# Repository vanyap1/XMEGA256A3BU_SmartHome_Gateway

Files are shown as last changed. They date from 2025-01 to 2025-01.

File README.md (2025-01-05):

# XMEGA256A3BU_SmartHome_Gateway

## Опис проекту
Це шлюз для розумного будинку, який може з'єднувати різні типи пристроїв з різними інтерфейсами, передавати та буферизувати між ними інформацію, реалізувати власну логіку та багато іншого.

## Можливості
- Підтримка інтерфейсів: LAN, CAN, SPI, I2C, GPIO
- Релейні виходи та входи з оптичною розв'язкою
- SD карта для логів
- Веб сервер для керування

## Структура проекту
- **XMEGA_A3BU**: Основний код проекту
  - `main.c`: Головний файл програми
  - `driver/`: Драйвери для різних периферійних пристроїв
  - `libs/`: Бібліотеки для роботи з різними інтерфейсами та пристроями
- **eagle_src**: Схеми та плати проекту
  - `controller_V1.brd`: Файл плати
  - `controller_V1.sch`: Схема проекту

## Контролер
В проекті використовується контролер **XMEGA256A3BU**. Основні переваги цього контролера:
- Висока продуктивність завдяки 8/16-бітному процесору
- Велика кількість периферійних інтерфейсів
- Низьке енергоспоживання
- Вбудована підтримка USB

## Фото модуля
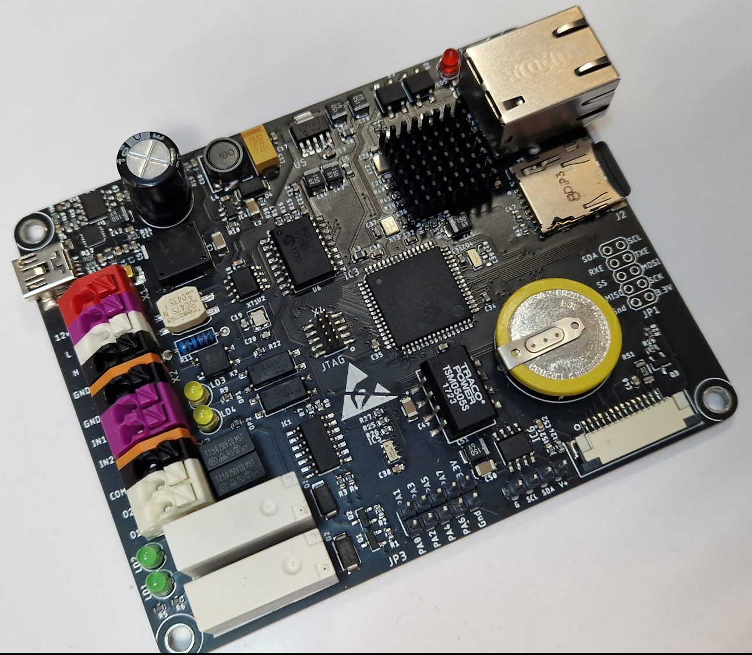
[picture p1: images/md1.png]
Фото модуля 1

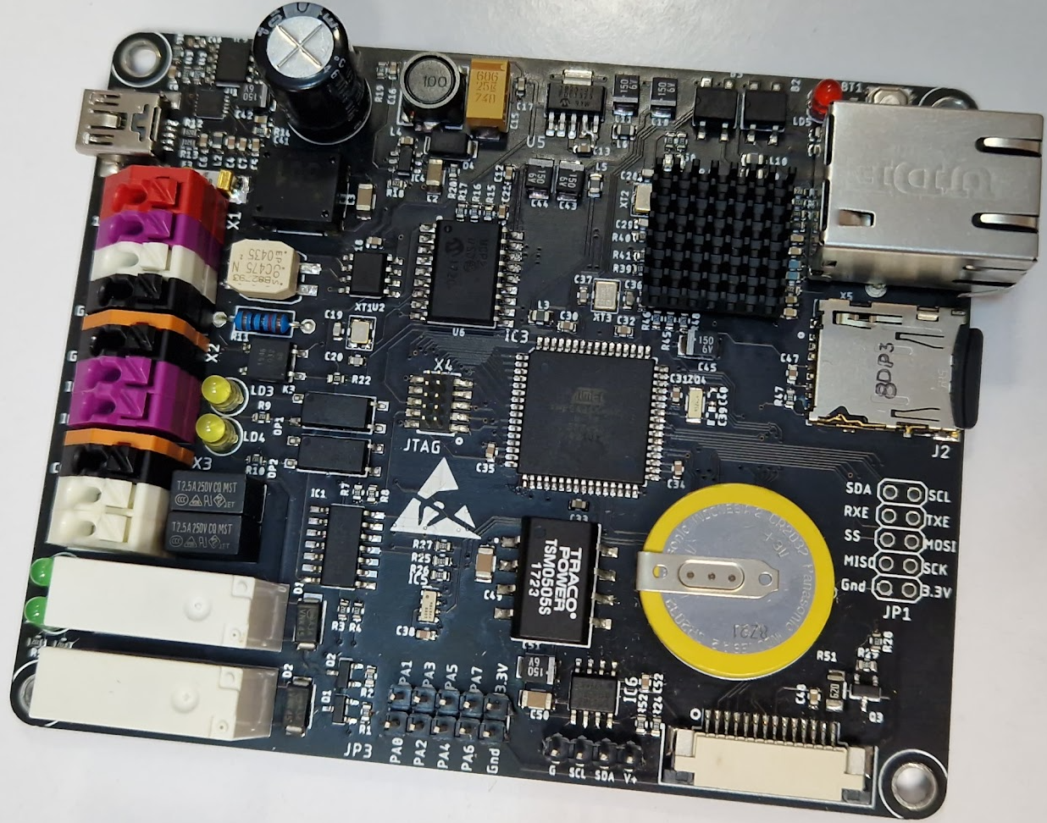
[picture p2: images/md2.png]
Фото модуля 2


## Інструкції по збірці
Для збірки проекту використовуйте Makefile, який знаходиться у директорії `XMEGA_A3BU/Debug/`.

```sh
cd XMEGA_A3BU/Debug/
make

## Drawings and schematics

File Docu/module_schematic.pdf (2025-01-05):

## FT234XD-R

# RTC_SDA USB

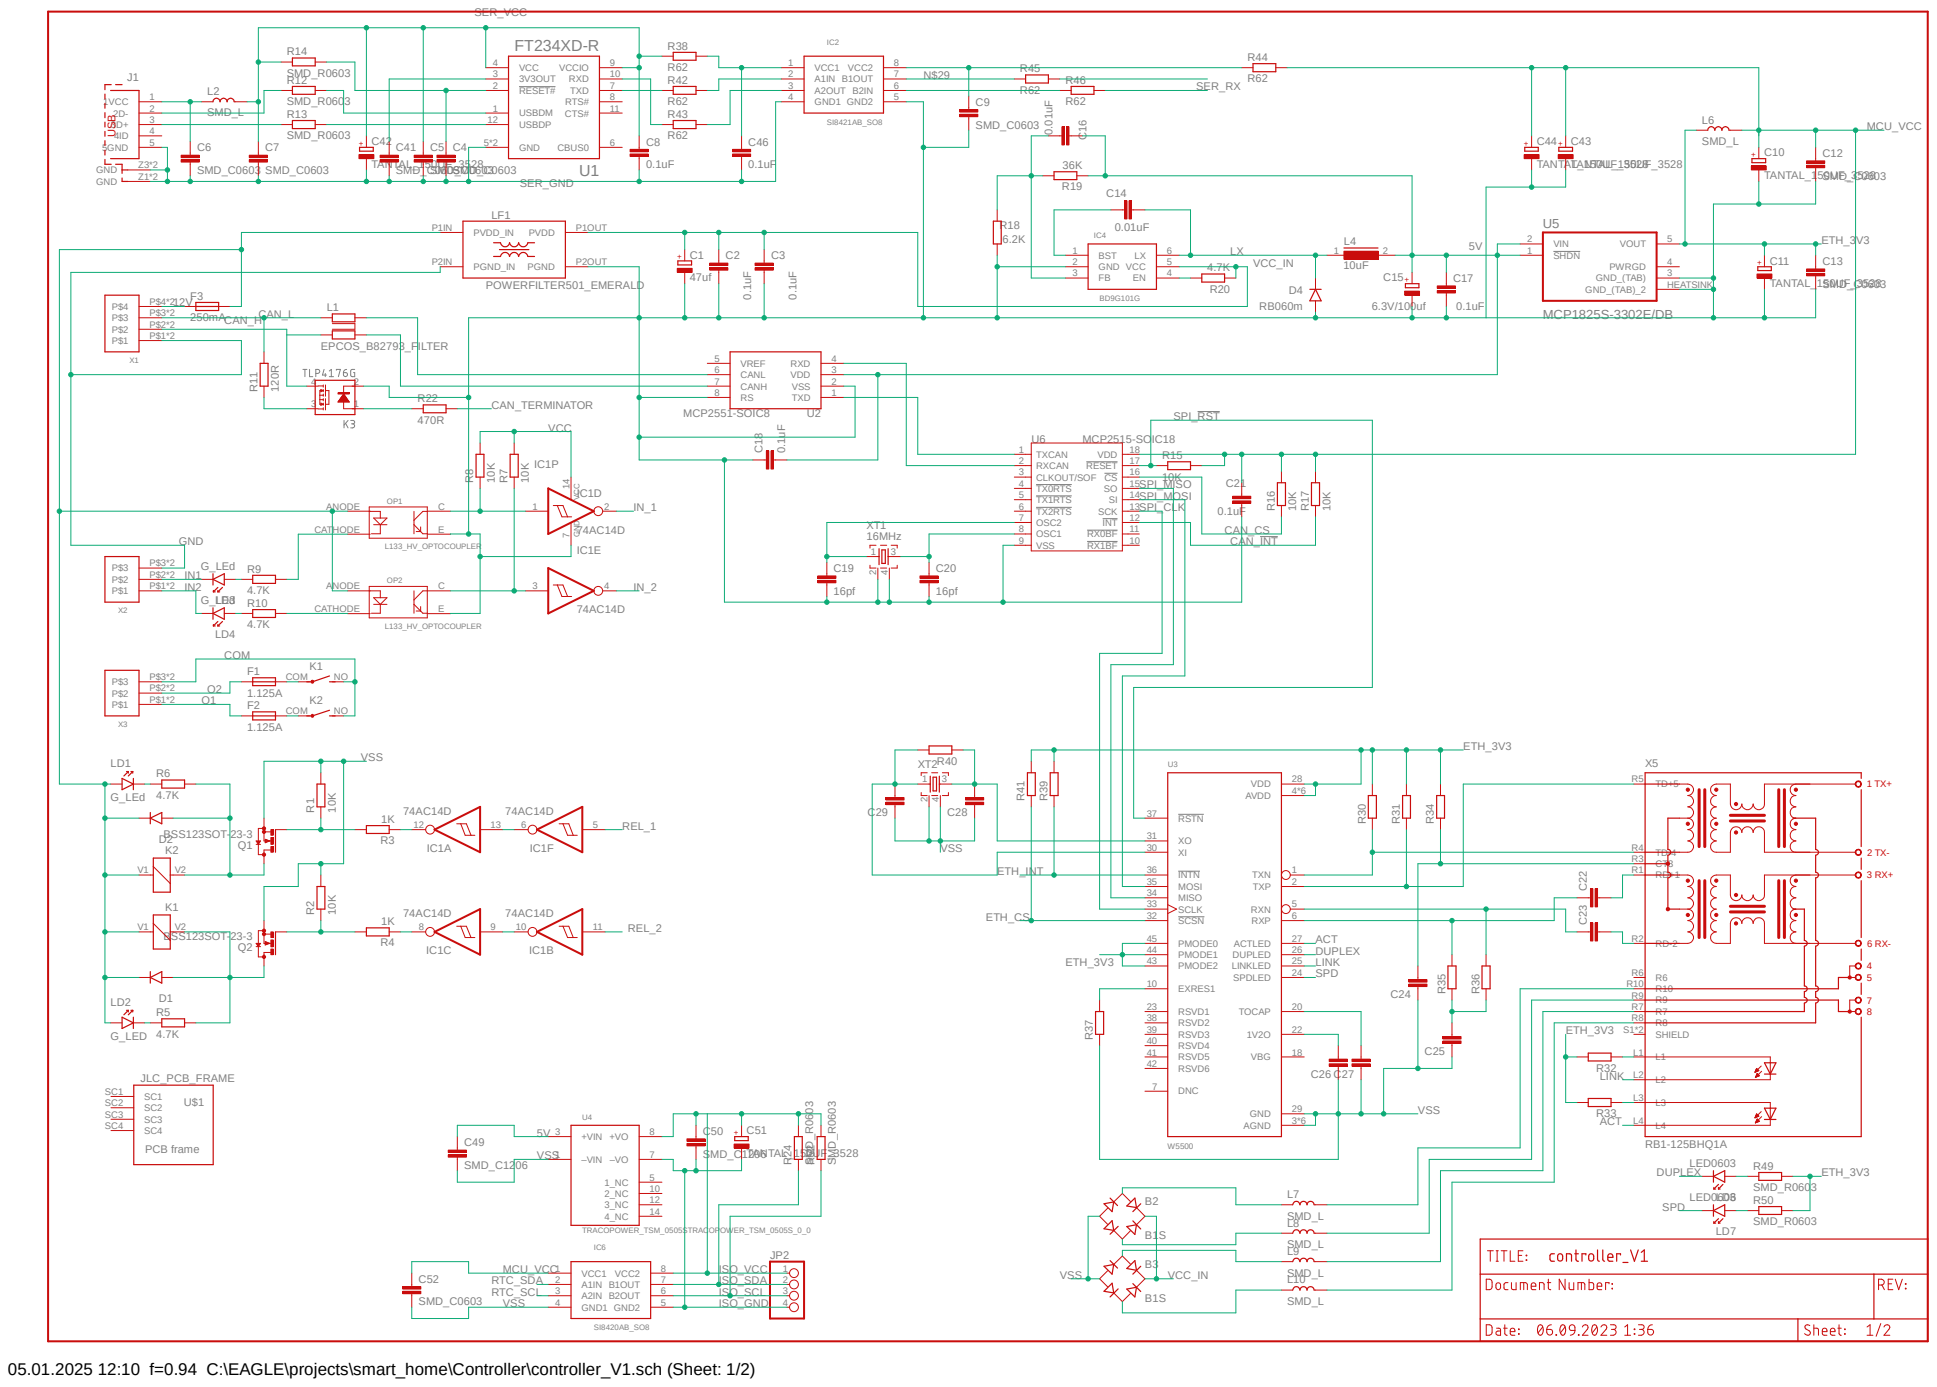
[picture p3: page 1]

05.01.2025 12:10 f=0.94 C:\EAGLE\projects\smart_home\Controller\controller_V1.sch (Sheet: 1/2)

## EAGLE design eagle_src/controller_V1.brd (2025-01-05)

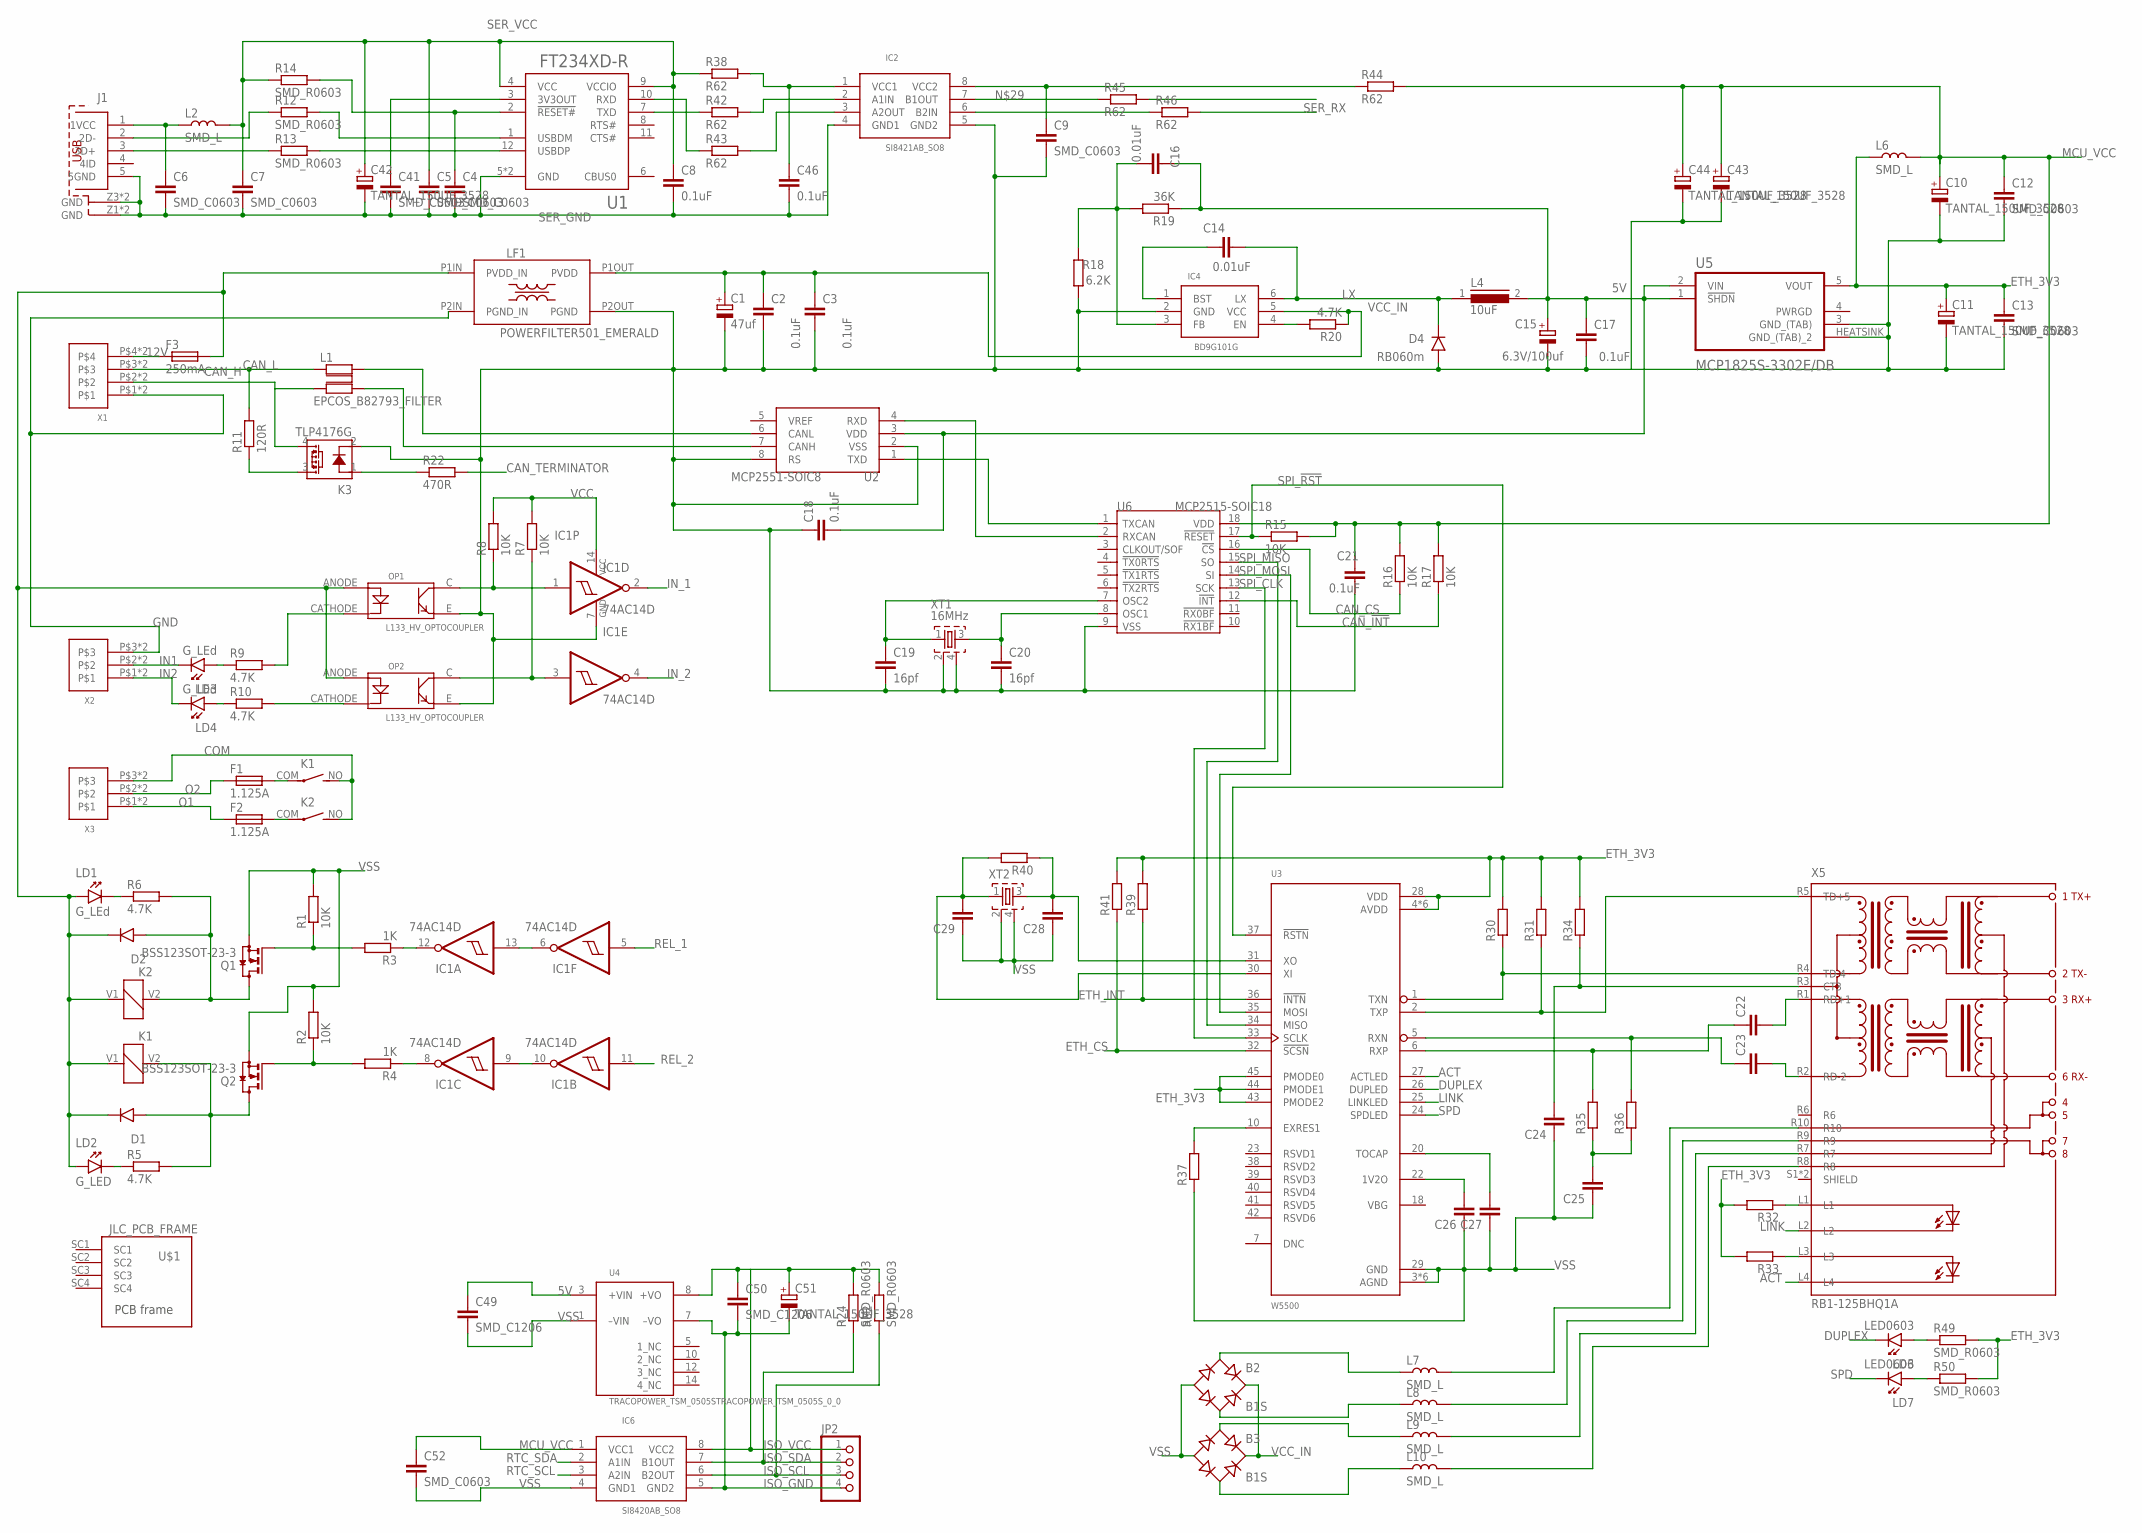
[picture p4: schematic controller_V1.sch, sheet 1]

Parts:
B2, B3: B1S; MBS
C1: 47uf; 5.08MM
C2, C3: 0.1uF; 1206
C4, C5, C6, C7, C9, C12, C13, C22, C23, C26, C27, C28, C29, C41, C52: SMD_C0603; 0603
C8, C17, C18, C21, C46: 0.1uF; 0603
C10, C11, C42, C43, C44, C51: TANTAL_150UF_3528; KA-3528ASYC
C14, C16: 0.01uF; 0603
C15: 6.3V/100uf; D/7343-31R
C19, C20: 16pf; 0603
C24: 0.1uf; 0603
C25: 10nf; 0603
C49, C50: SMD_C1206; 1206
D1, D2: D_MBRA340G; SMA403D
D4: RB060m; SMA403D
F1, F2: 1.125A; FUSE_DIP_2.5A250V
F3: 250mA; SMD_2410_FUSE_NOK
IC1: 74AC14D; SO14
IC2: SI8421AB_SO8; SO8
IC4: BD9G101G; SOT-23(6)
IC6: SI8420AB_SO8; SO8
J1: MINI_USB_TYP_B_@; 65100516121
JP2: PINHD-1X4; 1X04
K1, K2: 12-H1(610); 12-H1(610)_DIP
K3: TLP4176G; SOP04
L1: EPCOS_B82793_FILTER; EPCOS_FILTER
L2, L6, L7, L8, L9, L10: SMD_L; 0805
L4: 10uF; DR74
LD1, LD3, LD4: G_LEd; 3MM_DIP_LED
LD2: G_LED; 3MM_DIP_LED
LD6, LD7: LED0603; 0603_P
LF1: POWERFILTER501_EMERALD; POWERFILTER
OP1, OP2: L133_HV_OPTOCOUPLER; HV_OPTOCOUPLER_L133
Q1, Q2: BSS123SOT-23-3; SOT-23(3)
R1, R2, R7, R8, R15, R16, R17: 10K; 0603
R3, R4: 1K; 0603
R5, R6, R9, R10, R20: 4.7K; 0603
R11: 120R; VMTA55
R12, R13, R14, R24, R30, R31, R32, R33, R34, R35, R36, R37, R39, R40, R41, R49, R50, R52: SMD_R0603; 0603
R18: 6.2K; 0603
R19: 36K; 0603
R22: 470R; 0603
R38, R42, R43, R44, R45, R46: R62; 0603
U1: FT234XD-R; IC_FT234XD-R
U2: MCP2551-SOIC8; SO8
U3: W5500; QFP50P900X900X160-48N
U4: TRACOPOWER_TSM_0505STRACOPOWER_TSM_0505S_0_0; TRACOPOWER_TSM_0505S_0
U5: MCP1825S-3302E/DB; SOT230P700X180-4N
U6: MCP2515-SOIC18; SO18L
U$1: JLC_PCB_FRAME; 80X100_PCB_FRAME
X1: WAGO250_X4; WAGO250_FP_4X
X2, X3: WAGO250_X3; WAGO250_FP_3X
X5: RB1-125BHQ1A
XT1: 16MHz; QUARTZ_3X3MM
XT2: QUARTZ_ZQ; QUARTZ_3X3MM

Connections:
5V: C15.+, C16.2, C17.2, C18.2, C49.1, L4.2, R19.1, U2.3 (VDD), U4.3 (+VIN), U5.1 (!SHDN), U5.2 (VIN)
12V: F3.P$1 (1), X1.P$4, X1.U$4
ACT: U3.27 (ACTLED), X5.L4
CAN_!INT: R17.1, U6.12 (!INT); also elsewhere on the board
CAN_CS: R16.1, U6.16 (!CS); also elsewhere on the board
CAN_H: K3.4 (DS2), L1.P$2 (2), X1.P$2, X1.U$2
CAN_L: L1.P$1 (1), R11.2, X1.P$3, X1.U$3
CAN_TERMINATOR: R22.2; also elsewhere on the board
COM: K1.NO (S), K2.NO (S), X3.P$3, X3.U$3
DUPLEX: LD6.1 (K), U3.26 (DUPLED)
ETH_3V3: C11.P (+), C13.1, L6.1, R30.2, R31.2, R32.2, R33.2, R34.2, R39.2, R41.2, R49.2, R50.2, U3.4 (AVDD), U3.8 (AVDD), U3.11 (AVDD), U3.15 (AVDD), U3.17 (AVDD), U3.21 (AVDD), U3.28 (VDD), U3.43 (PMODE2), U3.44 (PMODE1), U3.45 (PMODE0), U5.5 (VOUT)
ETH_CS: R41.1, U3.32 (!SCSN); also elsewhere on the board
ETH_INT: R39.1, U3.36 (!INTN); also elsewhere on the board
GND: LF1.P2IN (PGND_IN), X1.P$1, X1.U$1, X2.P$3, X2.U$3
IN1: LD3.K, X2.P$2, X2.U$2
IN2: LD4.K, X2.P$1, X2.U$1
IN_1: IC1.2 (O); also elsewhere on the board
IN_2: IC1.4 (O); also elsewhere on the board
ISO_GND: C50.2, C51.M (-), IC6.5 (GND2), JP2.4, U4.7 (–VO)
ISO_SCL: IC6.6 (B2OUT), JP2.3, R52.1
ISO_SDA: IC6.7 (B1OUT), JP2.2, R24.1
ISO_VCC: C50.1, C51.P (+), IC6.8 (VCC2), JP2.1, R24.2, R52.2, U4.8 (+VO)
LINK: U3.25 (LINKLED), X5.L2
LX: C14.2, D4.P$1 (C), IC4.6 (LX), L4.1
MCU_VCC: C10.P (+), C12.1, C21.1, C43.P (+), C44.P (+), C52.1, IC6.1 (VCC1), L6.2, R15.2, R16.2, R17.2, R44.2, U6.18 (VDD); also elsewhere on the board
unnamed: IC2.3 (A2OUT), R43.2
unnamed: F1.P$2 (2), K1.COM
unnamed: F2.P$2 (2), K2.COM
unnamed: C41.1, U1.3 (3V3OUT)
unnamed: Q2.1 (G), R2.1, R4.2
unnamed: D1.P$2 (A), K1.V2 (2), Q2.3 (D), R5.2
unnamed: D2.P$2 (A), K2.V2 (2), Q1.3 (D), R6.2
unnamed: Q1.1 (G), R1.1, R3.2
unnamed: LD1.K, R6.1
unnamed: LD2.K, R5.1
unnamed: IC2.2 (A1IN), R42.2
unnamed: IC1.9 (I), IC1.10 (O)
unnamed: IC1.8 (O), R4.1
unnamed: IC1.6 (O), IC1.13 (I)
unnamed: IC1.12 (O), R3.1
unnamed: IC1.1 (I), OP1.C (COLLECTOR), R8.1
unnamed: IC1.3 (I), OP2.C (COLLECTOR), R7.1
unnamed: L10.2, X5.R8
unnamed: C46.1, IC2.1 (VCC1), R38.2
unnamed: D1.P$1 (C), D2.P$1 (C), F3.P$2 (2), K1.V1 (1), K2.V1 (1), LD1.A, LD2.A, LF1.P1IN (PVDD_IN), OP1.ANODE (ANOD), OP2.ANODE (ANOD)
unnamed: OP2.CATHODE (CATHOD), R10.2
unnamed: OP1.CATHODE (CATHOD), R9.2
unnamed: LD3.A, R9.1
unnamed: LD4.A, R10.1
unnamed: C9.1, IC2.8 (VCC2), R44.1
unnamed: IC2.7 (B1OUT), R45.1
unnamed: IC2.6 (B2IN), R46.1
unnamed: K3.3 (DS1), R11.1
unnamed: U2.1 (TXD), U6.1 (TXCAN)
unnamed: J1.3 (3D+), R13.1
unnamed: U2.4 (RXD), U6.2 (RXCAN)
unnamed: R13.2, U1.12 (USBDP)
unnamed: R12.2, U1.1 (USBDM)
unnamed: J1.2 (2D-), R12.1
unnamed: C4.1, R14.2, U1.2 (!RESET#)
unnamed: R42.1, U1.7 (TXD)
unnamed: C6.1, J1.1 (1VCC), L2.1
unnamed: L9.2, X5.R7
unnamed: L8.2, X5.R9
unnamed: R43.1, U1.10 (RXD)
unnamed: L1.P$3 (3), U2.7 (CANH)
unnamed: L1.P$4 (4), U2.6 (CANL)
unnamed: C14.1, IC4.1 (BST)
unnamed: L7.2, X5.R10
unnamed: C16.1, IC4.3 (FB), R18.2, R19.2
unnamed: IC4.4 (EN), R20.2
unnamed: C19.1, U6.7 (OSC2), XT1.1
unnamed: K3.1 (A), R22.1
unnamed: C20.1, U6.8 (OSC1), XT1.3
unnamed: B2.AC1, L7.1
unnamed: B2.AC2, L8.1
unnamed: B3.AC1, L9.1
unnamed: B3.AC2, L10.1
unnamed: LD6.2 (A), R49.1
unnamed: LD7.2 (A), R50.1
unnamed: C22.1, R35.2, U3.6 (RXP)
unnamed: C23.1, R36.2, U3.5 (RXN)
unnamed: R30.1, U3.1 (TXN), X5.R4 (TD-4)
unnamed: R31.1, U3.2 (TXP), X5.R5 (TD+5)
unnamed: C24.2, R34.1, X5.R3 (CT3)
unnamed: C25.2, R35.1, R36.1
unnamed: C22.2, X5.R1 (RD+1)
unnamed: C23.2, X5.R2 (RD-2)
unnamed: R32.1, X5.L1
unnamed: R33.1, X5.L3
unnamed: C26.2, U3.22 (1V2O)
unnamed: C27.2, U3.20 (TOCAP)
unnamed: R37.2, U3.10 (EXRES1)
unnamed: C29.2, R40.2, U3.30 (XI), XT2.1
unnamed: C28.2, R40.1, U3.31 (XO), XT2.3
O1: F2.P$1 (1), X3.P$1, X3.U$1
O2: F1.P$1 (1), X3.P$2, X3.U$2
REL_1: IC1.5 (I); also elsewhere on the board
REL_2: IC1.11 (I); also elsewhere on the board
RTC_SCL: IC6.3 (A2IN); also elsewhere on the board
RTC_SDA: IC6.2 (A1IN); also elsewhere on the board
SER_GND: C4.2, C5.2, C6.2, C7.2, C8.2, C41.2, C42.M (-), C46.2, IC2.4 (GND1), J1.5 (5GND), J1.Z1 (GND), J1.Z2 (GND), J1.Z3 (GND), J1.Z4 (GND), U1.5 (GND), U1.13 (GND)
SER_RX: R46.2; also elsewhere on the board
SER_TX: R45.2; also elsewhere on the board
SER_VCC: C5.1, C7.1, C8.1, C42.P (+), L2.2, R14.1, R38.1, U1.4 (VCC), U1.9 (VCCIO)
SPD: LD7.1 (K), U3.24 (SPDLED)
SPI_!RST: R15.1, U3.37 (!RSTN), U6.17 (!RESET); also elsewhere on the board
SPI_CLK: U3.33 (SCLK), U6.13 (SCK); also elsewhere on the board
SPI_MISO: U3.34 (MISO), U6.15 (SO); also elsewhere on the board
SPI_MOSI: U3.35 (MOSI), U6.14 (SI); also elsewhere on the board
VCC: IC1.14 (VCC), R7.2, R8.2; also elsewhere on the board
VCC_IN: B2.+, B3.+, C1.P$2 (+), C2.1, C3.1, IC4.5 (VCC), LF1.P1OUT (PVDD), R20.1
VSS: B2.-, B3.-, C1.P$1 (-), C2.2, C3.2, C9.2, C10.M (-), C11.M (-), C12.2, C13.2, C15.-, C17.1, C18.1, C19.2, C20.2, C21.2, C24.1, C25.1, C26.1, C27.1, C28.1, C29.1, C43.M (-), C44.M (-), C49.2, C52.2, D4.P$2 (A), IC1.7 (GND), IC2.5 (GND2), IC4.2 (GND), IC6.4 (GND1), K3.2 (K), LF1.P2OUT (PGND), OP1.E (EMITTER), OP2.E (EMITTER), Q1.2 (S), Q2.2 (S), R1.2, R2.2, R18.1, R37.1, U2.2 (VSS), U2.8 (RS), U3.3 (AGND), U3.9 (AGND), U3.14 (AGND), U3.16 (AGND), U3.19 (AGND), U3.29 (GND), U3.48 (AGND), U4.1 (–VIN), U5.3 (GND_(TAB)), U5.HEATSINK (GND_(TAB)_2), U6.9 (VSS), XT1.2, XT1.4, XT2.2, XT2.4; also elsewhere on the board

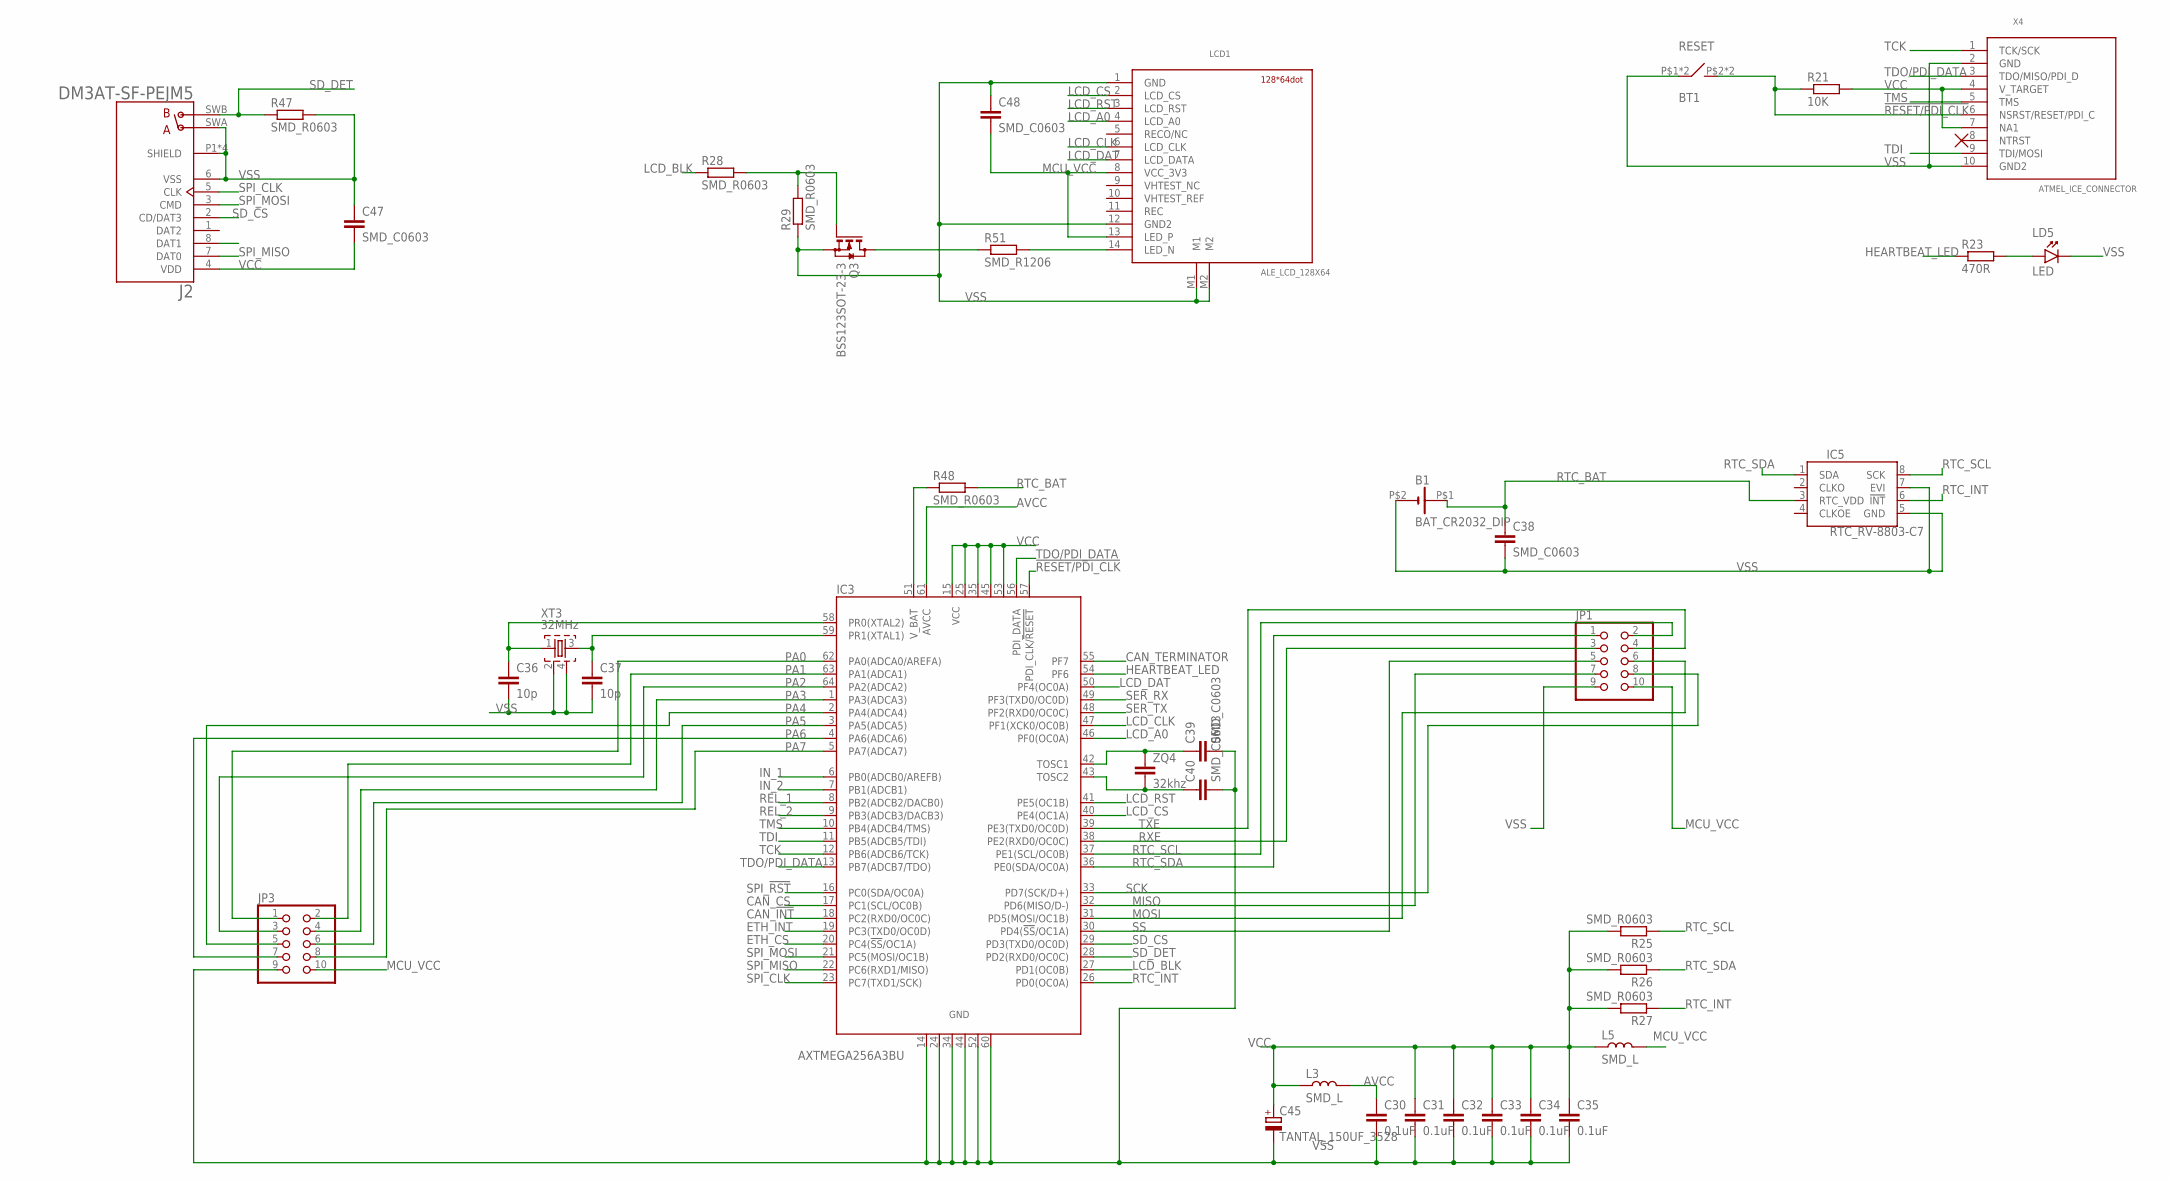
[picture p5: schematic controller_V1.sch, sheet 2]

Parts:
B1: BAT_CR2032_DIP; CR2032_DIP
BT1: RESET; 5X5MM_SMD_CY
C30, C31, C32, C33, C34, C35: 0.1uF; 0603
C36, C37: 10p; 0603
C38, C39, C40, C47, C48: SMD_C0603; 0603
C45: TANTAL_150UF_3528; KA-3528ASYC
IC3: AXTMEGA256A3BU; TQFP64
IC5: RTC_RV-8803-C7; C7_RTC
J2: DM3AT-SF-PEJM5; HRS_DM3AT-SF-PEJM5
JP1, JP3: PINHD-2X5; 2X05
L3, L5: SMD_L; 0805
LCD1: ALE_LCD_128X64; ALE_LCD_14PIN_CONNECTOR
LD5: LED; 3MM_DIP_LED
Q3: BSS123SOT-23-3; SOT-23(3)
R21: 10K; 0603
R23: 470R; 0603
R25, R26, R27, R28, R29, R47, R48: SMD_R0603; 0603
R51: SMD_R1206; 1206
X4: ATMEL_ICE_CONNECTOR; MINI10P_SPI/JTAG/PDI
XT3: 32MHz; QUARTZ_3X3MM
ZQ4: 32khz; 1206

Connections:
!RESET/PDI_CLK: BT1.P$2 (4), BT1.P$3 (4), IC3.57 (PDI_CLK/!RESET!), R21.1, X4.6 (NSRST/RESET/PDI_C)
AVCC: C30.1, IC3.61 (AVCC), L3.2
CAN_!INT: IC3.18 (PC2(RXD0/OC0C)); also elsewhere on the board
CAN_CS: IC3.17 (PC1(SCL/OC0B)); also elsewhere on the board
CAN_TERMINATOR: IC3.55 (PF7); also elsewhere on the board
ETH_CS: IC3.20 (PC4(!SS!/OC1A)); also elsewhere on the board
ETH_INT: IC3.19 (PC3(TXD0/OC0D)); also elsewhere on the board
HEARTBEAT_LED: IC3.54 (PF6), R23.1
IN_1: IC3.6 (PB0(ADCB0/AREFB)); also elsewhere on the board
IN_2: IC3.7 (PB1(ADCB1)); also elsewhere on the board
LCD_A0: IC3.46 (PF0(OC0A)), LCD1.4 (LCD_A0)
LCD_BLK: IC3.27 (PD1(OC0B)), R28.1
LCD_CLK: IC3.47 (PF1(XCK0/OC0B)), LCD1.6 (LCD_CLK)
LCD_CS: IC3.40 (PE4(OC1A)), LCD1.2 (LCD_CS)
LCD_DAT: IC3.50 (PF4(OC0A)), LCD1.7 (LCD_DATA)
LCD_RST: IC3.41 (PE5(OC1B)), LCD1.3 (LCD_RST)
MCU_VCC: C48.2, JP1.10, JP3.10, L5.2, LCD1.8 (VCC_3V3), LCD1.13 (LED_P); also elsewhere on the board
MISO: IC3.32 (PD6(MISO/D-)), JP1.7
MOSI: IC3.31 (PD5(MOSI/OC1B)), JP1.6
unnamed: C36.1, IC3.58 (PR0(XTAL2)), XT3.1
unnamed: C37.1, IC3.59 (PR1(XTAL1)), XT3.3
unnamed: LD5.A, R23.2
unnamed: IC3.51 (V_BAT), R48.1
unnamed: Q3.3 (D), R51.1
unnamed: LCD1.14 (LED_N), R51.2
unnamed: C40.1, IC3.43 (TOSC2), ZQ4.2
unnamed: C39.1, IC3.42 (TOSC1), ZQ4.1
unnamed: Q3.1 (G), R28.2, R29.2
PA0: IC3.62 (PA0(ADCA0/AREFA)), JP3.1
PA1: IC3.63 (PA1(ADCA1)), JP3.2
PA2: IC3.64 (PA2(ADCA2)), JP3.3
PA3: IC3.1 (PA3(ADCA3)), JP3.4
PA4: IC3.2 (PA4(ADCA4)), JP3.5
PA5: IC3.3 (PA5(ADCA5)), JP3.6
PA6: IC3.4 (PA6(ADCA6)), JP3.7
PA7: IC3.5 (PA7(ADCA7)), JP3.8
REL_1: IC3.8 (PB2(ADCB2/DACB0)); also elsewhere on the board
REL_2: IC3.9 (PB3(ADCB3/DACB3)); also elsewhere on the board
RTC_BAT: B1.P$1 (+), C38.1, IC5.3 (RTC_VDD), R48.2
RTC_INT: IC3.26 (PD0(OC0A)), IC5.6 (!INT), R27.1
RTC_SCL: IC3.37 (PE1(SCL/OC0B)), IC5.8 (SCK), JP1.2, R25.1; also elsewhere on the board
RTC_SDA: IC3.36 (PE0(SDA/OC0A)), IC5.1 (SDA), JP1.1, R26.1; also elsewhere on the board
RXE: IC3.38 (PE2(RXD0/OC0C)), JP1.3
SCK: IC3.33 (PD7(SCK/D+)), JP1.8
SD_CS: IC3.29 (PD3(TXD0/OC0D)), J2.2 (CD/DAT3)
SD_DET: IC3.28 (PD2(RXD0/OC0C)), J2.SWB (B), R47.1
SER_RX: IC3.49 (PF3(TXD0/OC0D)); also elsewhere on the board
SER_TX: IC3.48 (PF2(RXD0/OC0C)); also elsewhere on the board
SPI_!RST: IC3.16 (PC0(SDA/OC0A)); also elsewhere on the board
SPI_CLK: IC3.23 (PC7(TXD1/SCK)), J2.5 (CLK); also elsewhere on the board
SPI_MISO: IC3.22 (PC6(RXD1/MISO)), J2.7 (DAT0); also elsewhere on the board
SPI_MOSI: IC3.21 (PC5(MOSI/OC1B)), J2.3 (CMD); also elsewhere on the board
SS: IC3.30 (PD4(!SS!/OC1A)), JP1.5
TCK: IC3.12 (PB6(ADCB6/TCK)), X4.1 (TCK/SCK)
TDI: IC3.11 (PB5(ADCB5/TDI)), X4.9 (TDI/MOSI)
TDO/PDI_DATA: IC3.13 (PB7(ADCB7/TDO)), IC3.56 (PDI_DATA), X4.3 (TDO/MISO/PDI_D)
TMS: IC3.10 (PB4(ADCB4/TMS)), X4.5 (TMS)
TXE: IC3.39 (PE3(TXD0/OC0D)), JP1.4
VCC: C31.1, C32.1, C33.1, C34.1, C35.1, C45.P (+), C47.2, IC3.15 (VCC1), IC3.25 (VCC2), IC3.35 (VCC3), IC3.45 (VCC4), IC3.53 (VCC5), J2.4 (VDD), L3.1, L5.1, R21.2, R25.2, R26.2, R27.2, X4.4 (V_TARGET), X4.7 (NA1); also elsewhere on the board
VSS: B1.P$2 (-), BT1.P$1 (1), BT1.P$4 (1), C30.2, C31.2, C32.2, C33.2, C34.2, C35.2, C36.2, C37.2, C38.2, C39.2, C40.2, C45.M (-), C47.1, C48.1, IC3.14 (GND1), IC3.24 (GND2), IC3.34 (GND3), IC3.44 (GND4), IC3.52 (GND5), IC3.60 (GND6), IC5.5 (GND), IC5.7 (EVI), J2.6 (VSS), J2.P1 (SHIELD), J2.P2 (SHIELD), J2.P3 (SHIELD), J2.P4 (SHIELD), J2.SWA (A), JP1.9, JP3.9, LCD1.1 (GND), LCD1.12 (GND2), LCD1.M1, LCD1.M2, LD5.K, Q3.2 (S), R29.1, R47.2, X4.2 (GND), X4.10 (GND2), XT3.2, XT3.4; also elsewhere on the board

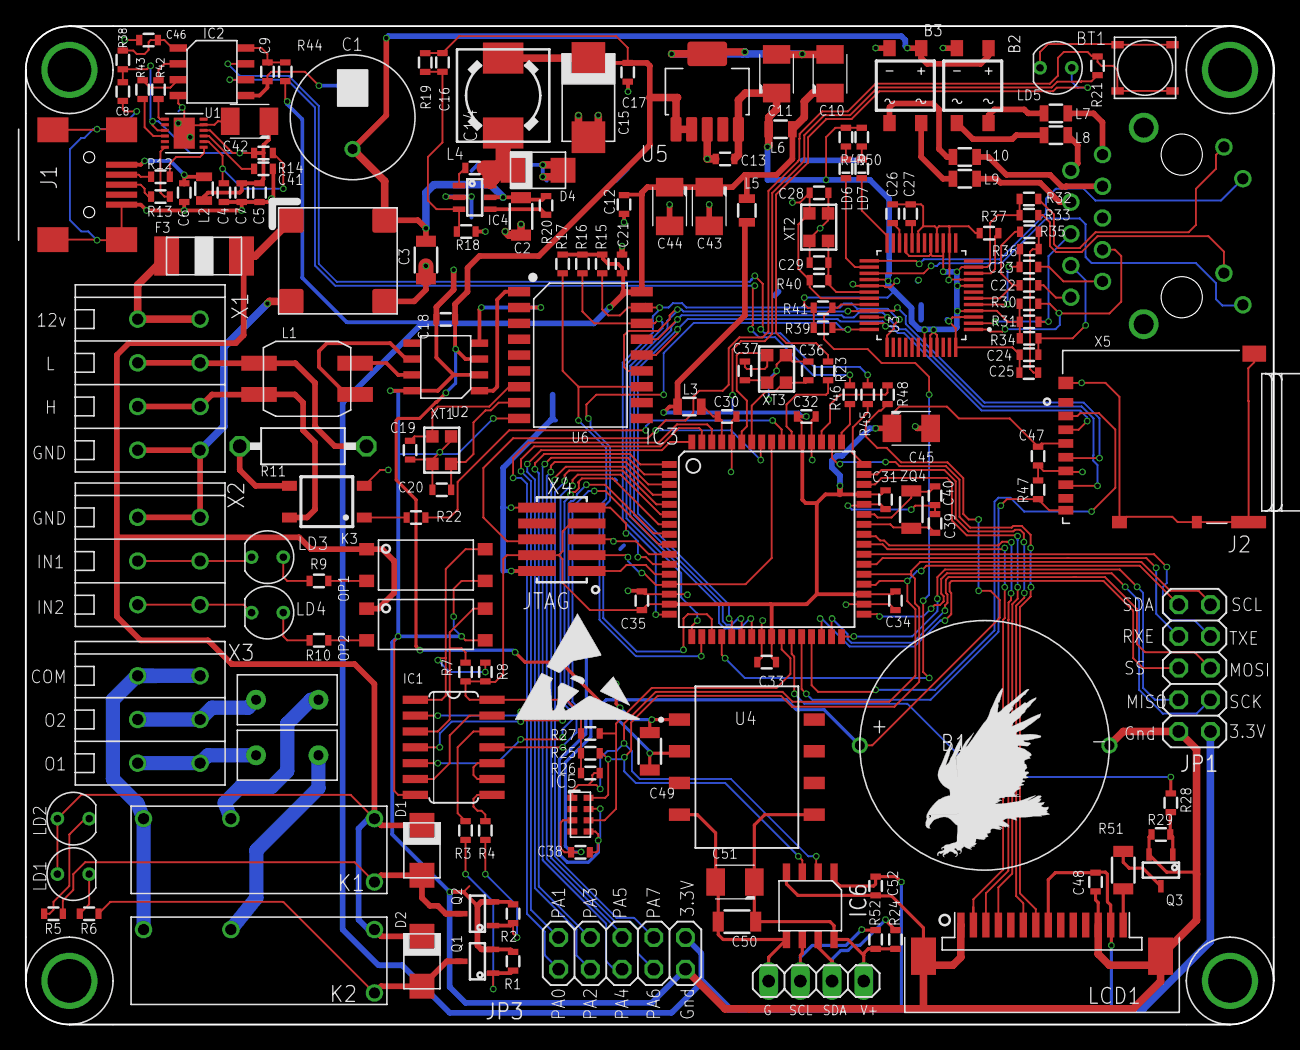
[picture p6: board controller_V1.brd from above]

Board: 2 copper layers, 100.0 x 80.0 mm, 171 parts (1 on the bottom side), 153 nets.

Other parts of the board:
U$2, U$4: EAGLE-PLC-10MM
U$3: ESD_10.00

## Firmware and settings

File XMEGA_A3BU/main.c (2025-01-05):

/*
 * XMEGA_A3BU.c
 *
 * Created: 02.01.2025 12:08:44
 * Author : Ivan Prints
 */ 

#include "config.h"
#include <avr/io.h>
#include <util/delay.h>
#include <avr/interrupt.h>
#include <stdbool.h>
#include "spic_driver.h"
#include "twie_driver.h"
#include "gpio_driver.h"
#include "debugSerial.h"
#include "sysTickTimer.h"
#include "rtc.h"
#include "socket.h"
#include "netHandler.h"
#include "canspi.h"

rtc_date sys_rtc = {
	.date = 4,
	.month = 1,
	.year = 25,
	.dayofweek = 6,
	.hour = 0,
	.minute = 8,
	.second = 00
};


gpio hbRedLed = {(uint8_t *)&PORTF , PIN6_bp};
	
gpio in1 = {(uint8_t *)&PORTB , PIN0_bp};
gpio in2 = {(uint8_t *)&PORTB , PIN1_bp};
gpio rel1 = {(uint8_t *)&PORTB , PIN2_bp};
gpio rel2 = {(uint8_t *)&PORTB , PIN3_bp};


uCAN_MSG txMessage;
uCAN_MSG rxMessage;
	

/*
MCU - OK
SPIC - (LAN, CAN, SD) - OK
LAN - OK
CAN - OK
GPIO - OK
UART - OK (printf)
TWIE
	RTC
	i2c-rtc INT pin handler
move index.html to PROGMEM

TODO -
	SD Card
	RTC mcu	
*/
uint8_t tmpData;

int main(void)
{
	
	OSC.CTRL |= OSC_RC32MEN_bm;
	while ((OSC.STATUS & OSC_RC32MRDY_bm) == 0)
	_PROTECTED_WRITE(CLK.CTRL, CLK_SCLKSEL_RC32M_gc);
	gpio_set_pin_direction(&hbRedLed , PORT_DIR_OUT); 
	gpio_set_pin_direction(&in1 , PORT_DIR_IN); 
	gpio_set_pin_direction(&in2 , PORT_DIR_IN);
	gpio_set_pin_direction(&rel1 , PORT_DIR_OUT);
	gpio_set_pin_direction(&rel2 , PORT_DIR_OUT);
	
	gpio_set_pin_level(&hbRedLed, true);
	gpio_set_pin_level(&hbRedLed, false);
	
	sei();
	debugSerialInit(DEB_SERIAL_BAUD);
	initSpic();
	netInit();
	CANSPI_Initialize();
	twieInit();
	rtc_int_enable();
	//rtc_set(&sys_rtc);
	sysTickInit();
	
	while (1) 
    {
		gpio_toggle_pin_level(&hbRedLed);
		
		gpio_set_pin_level(&rel1, gpio_get_pin_level(&in1));
		gpio_set_pin_level(&rel2, gpio_get_pin_level(&in2));
		
		//_delay_ms(20);
		
		
		 if(CANSPI_Receive(&rxMessage))
		 {
			 gpio_toggle_pin_level(&hbRedLed);
		 }
		tmpData = getRxByte();
		uint8_t tmpChr;
		if(tmpData != 0){
			tmpChr = 10;
		}

		if(getRtcInt()){
			rtc_sync(&sys_rtc);
			printf("RTC %d-%d-%d %d; %d:%d:%d %d; %d \n", sys_rtc.date, sys_rtc.month, sys_rtc.year, sys_rtc.dayofweek, sys_rtc.hour, sys_rtc.minute, sys_rtc.second, getRxByte(), getUpTime());
			
			txMessage.frame.idType = dSTANDARD_CAN_MSG_ID_2_0B;
			txMessage.frame.id = 0x0A;
			txMessage.frame.dlc = 8;
			txMessage.frame.data0 = 0;
			txMessage.frame.data1 = 1;
			txMessage.frame.data2 = 2;
			txMessage.frame.data3 = 3;
			txMessage.frame.data4 = 4;
			txMessage.frame.data5 = 5;
			txMessage.frame.data6 = 6;
			txMessage.frame.data7 = 7;
			CANSPI_Transmit(&txMessage);
		}
		
		
		netHandler();
		
    }
	
	return 0;
}

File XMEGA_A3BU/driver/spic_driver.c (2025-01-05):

/*
 * spi_driver.c
 *
 * Created: 02.01.2025 15:58:21
 *  Author: Ivan Prints
 */ 

#include "spic_driver.h"



gpio SPI_RST = {(uint8_t *)&PORTC , PIN0_bp};
gpio CAN_CS = {(uint8_t *)&PORTC , PIN1_bp};
gpio CAN_INT = {(uint8_t *)&PORTC , PIN2_bp};
gpio CAN_TERM = {(uint8_t *)&PORTF , PIN7_bp};
gpio ETH_INT = {(uint8_t *)&PORTC , PIN3_bp};
gpio ETH_CS = {(uint8_t *)&PORTC , PIN4_bp};

gpio SD_CS = {(uint8_t *)&PORTD , PIN3_bp};
gpio SD_DET = {(uint8_t *)&PORTD , PIN2_bp};
gpio LCD_BLK = {(uint8_t *)&PORTD , PIN1_bp};
gpio RTC_INT = {(uint8_t *)&PORTD , PIN0_bp};
	
	


uint8_t initSpic(void){
	PORTC.DIRSET = PIN4_bm | PIN5_bm | PIN7_bm; // SCK, MOSI, SS - ?? ??????
	PORTC.DIRCLR = PIN6_bm;                     // MISO - ?? ????
	
	SPIC.CTRL = (0 << SPIC_CLK2X) | (1 << SPIC_ENABLE) | (0 << SPIC_DORD) | (1 << SPIC_MASTER) | (0b00 << SPIC_MODE) | (0b00 << SPIC_PRESCALLER);
	//SPIC.CTRL = SPI_ENABLE_bm | SPI_MASTER_bm | SPI_MODE_0_gc | SPI_PRESCALER_DIV4_gc;
	
	gpio_set_pin_direction(&SPI_RST , PORT_DIR_OUT);
	gpio_set_pin_direction(&CAN_CS , PORT_DIR_OUT);
	gpio_set_pin_direction(&ETH_CS , PORT_DIR_OUT);
	gpio_set_pin_direction(&SD_CS , PORT_DIR_OUT);
	gpio_set_pin_direction(&LCD_BLK , PORT_DIR_OUT);
	gpio_set_pin_direction(&CAN_TERM , PORT_DIR_OUT);
	
	gpio_set_pin_direction(&CAN_INT , PORT_DIR_IN);
	gpio_set_pin_direction(&ETH_INT , PORT_DIR_IN);
	gpio_set_pin_direction(&RTC_INT , PORT_DIR_IN);
	gpio_set_pin_direction(&SD_DET , PORT_DIR_IN);
	
	gpio_set_pin_level(&SPI_RST, false);
	_delay_ms(50);
	
	gpio_set_pin_level(&CAN_CS, true);
	gpio_set_pin_level(&ETH_CS, true);
	gpio_set_pin_level(&SD_CS, true);
	
	gpio_set_pin_level(&SPI_RST, true);
	return 1;
}

void spicTransfer(uint8_t *data, uint16_t len) {
	for (uint16_t i = 0; i < len; i++) {
		SPIC.DATA = data[i];               
		while (!(SPIC.STATUS & SPI_IF_bm)); 
		data[i] = SPIC.DATA;              
	}
}

void spicTxBuff(uint8_t *tx,uint16_t len){
	for(uint16_t i=0; i < len;i++){
		SPIC.DATA = tx[i];
		while (!(SPIC.STATUS & SPI_IF_bm));
	}
}

void spicRxBuff(uint8_t *tx,uint16_t len){
	for(uint16_t i=0; i < len;i++){
		SPIC.DATA = DUMMY_BYTE;
		while (!(SPIC.STATUS & SPI_IF_bm));
		tx[i] = SPIC.DATA;
	}
}

uint8_t spicRxByte(void){
	SPIC.DATA = DUMMY_BYTE;
	while (!(SPIC.STATUS & SPI_IF_bm));
	return SPIC.DATA;
}

void spicTxByte(uint8_t byte){
	SPIC.DATA = byte;
	while (!(SPIC.STATUS & SPI_IF_bm));
}

uint8_t spicRxTXByte(uint8_t byte){
	SPIC.DATA = byte;
	while (!(SPIC.STATUS & SPI_IF_bm));
	return SPIC.DATA;
}


void CAN_Select(void){
	gpio_set_pin_level(&CAN_CS, false);
}
void CAN_Unselect(void){
	gpio_set_pin_level(&CAN_CS, true);
}

uint8_t CAN_GetIntPin(void){
	return gpio_get_pin_level(&CAN_INT);
}

void SD_Select(void){
	gpio_set_pin_level(&SD_CS, false);
}
void SD_Unselect(void){
	gpio_set_pin_level(&SD_CS, true);
}

void W5500_Select(void){
	gpio_set_pin_level(&ETH_CS, false);
}
void W5500_Unselect(void){
	gpio_set_pin_level(&ETH_CS, true);
}
void W5500_ReadBuff(uint8_t* buff, uint16_t len){
	spicRxBuff(buff, len);
}
void W5500_WriteBuff(uint8_t* buff, uint16_t len){
	spicTxBuff(buff, len);
}
uint8_t W5500_ReadByte(void){
	return spicRxByte();
}
void W5500_Write_byte(uint8_t byte){
	spicTxByte(byte);
}

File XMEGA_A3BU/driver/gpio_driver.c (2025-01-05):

/*
 * gpio_driver.c
 *
 * Created: 02.01.2025 19:07:26
 *  Author: Ivan Prints
 */ 
#include "gpio_driver.h"



void gpio_set_pin_level(gpio *GPIOx, const bool level){
	uint8_t *tmp_port = GPIOx->port+4;
	if (level) {
		*tmp_port |= 1 << GPIOx->pin;
		} else {
		*tmp_port &= ~(1 << GPIOx->pin);
	}
}
void gpio_set_port_level(gpio *GPIOx, const uint8_t mask){
	
}
void gpio_set_pin_direction(gpio *GPIOx, const enum port_dir direction){
	
	uint8_t *tmp_port = GPIOx->port;
	
	switch (direction) {
		case PORT_DIR_IN:
		*tmp_port &= ~(1 << GPIOx->pin);
		break;
		case PORT_DIR_OUT:
		*tmp_port |= 1 << GPIOx->pin;
		break;
		case PORT_DIR_OFF:
		*tmp_port &= ~(1 << GPIOx->pin);
		*GPIOx->port &= ~(1 << GPIOx->pin);
		break;
		default:
		break;
	}
}
void gpio_set_pin_pull_mode(gpio *GPIOx, const enum port_pull_mode pull_mode){
	
}
void gpio_set_port_direction(gpio *GPIOx, const uint8_t mask){
	
}
uint8_t gpio_get_port_level(gpio *GPIOx){
	return 0;	
}


uint8_t gpio_get_pin_level(gpio *GPIOx){
	uint8_t *tmp_port = GPIOx->port+8;
	return *tmp_port & (1 << GPIOx->pin); 
}
void gpio_toggle_pin_level(gpio *GPIOx){
	uint8_t *tmp_port = GPIOx->port+7;
	*tmp_port |= 1 << GPIOx->pin;
}
